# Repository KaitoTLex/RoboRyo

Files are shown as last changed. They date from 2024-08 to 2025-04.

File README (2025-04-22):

This is the Robo Ryo Repository

The RoboRyo is a more redundant clone of National Intstrument's RoboRio. It provides long range controls and less BS compared to the FRC legal RoboRio. The upside of RoboRyo is that there are more configurable ports compared to the real RoboRyo and it also includes quality of Life features that the real RoboRio dosen't have. 

This document gives you an overview of the RoboRyo repository and how it works 

Contributers

The RoboRyo PCB is designed by KaitoTLex(Ren Lin)
The RoboRyo Code is developed by Nichloas Luo

This project is licened under the MIT License

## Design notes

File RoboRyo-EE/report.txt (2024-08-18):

Info: Processing symbol 'C1:CAPC1608X90N'.
Info: Processing symbol 'DO7:26011102'.
Info: Processing symbol 'C2:CAPC0603X33N'.
Info: Processing symbol 'J4:26011103'.
Info: Processing symbol 'C3:CAPC0603X33N'.
Info: Processing symbol 'J3:26011103'.
Info: Processing symbol 'C4:CAPC0603X33N'.
Info: Processing symbol 'J2:26011103'.
Info: Processing symbol 'C5:CAPC0603X33N'.
Info: Processing symbol 'J1:26011103'.
Info: Processing symbol 'C6:CAPC0603X33N'.
Info: Processing symbol 'IC3:LD29080DT50R'.
Info: Processing symbol 'C9:CAPC0603X33N'.
Info: Processing symbol 'IC2:TO228P972X240-3N'.
Info: Processing symbol 'C13:CAPC0603X33N'.
Info: Processing symbol 'IC1:XB24CAWIT001'.
Info: Processing symbol 'C14:CAPC1608X90N'.
Info: Processing symbol 'DO1:26011102'.
Info: Processing symbol 'C16:CAPC1608X90N'.
Info: Processing symbol 'DO12:26011102'.
Info: Processing symbol 'CAN1:26011102'.
Info: Processing symbol 'DO2:26011102'.
Info: Processing symbol 'D1:DIOAD1910W86L670D310'.
Info: Processing symbol 'DO8:26011102'.
Info: Processing symbol 'D2:DIOAD1910W86L670D310'.
Info: Processing symbol 'DO3:26011102'.
Info: Processing symbol 'D3:DIOAD1910W86L670D310'.
Info: Processing symbol 'DO11:26011102'.
Info: Processing symbol 'D6:DIOAD1910W86L670D310'.
Info: Processing symbol 'DO4:26011102'.
Info: Processing symbol 'D7:DIOAD1910W86L670D310'.
Info: Processing symbol 'DO9:26011102'.
Info: Processing symbol 'D8:DIOAD1910W86L670D310'.
Info: Processing symbol 'DO5:26011102'.
Info: Processing symbol 'D9:DIOAD1910W86L670D310'.
Info: Processing symbol 'DO13:26011102'.
Info: Processing symbol 'D10:DIOAD1910W86L670D310'.
Info: Processing symbol 'DO6:26011102'.
Info: Processing symbol 'D11:DIOAD1910W86L670D310'.
Info: Processing symbol 'DO10:26011102'.
Info: Processing symbol 'D12:DIOAD1910W86L670D310'.
Info: Processing symbol 'J5:26011103'.
Info: Processing symbol 'J6:26011103'.
Info: Processing symbol 'J7:26011103'.
Info: Processing symbol 'J8:26011103'.
Info: Processing symbol 'LED1-A1:LEDC1608X80N'.
Info: Processing symbol 'LED1-B1:LEDC1608X80N'.
Info: Processing symbol 'LED1-G1:LEDC1608X80N'.
Info: Processing symbol 'LED1-R1:LEDC1608X80N'.
Info: Processing symbol 'LED1-Y1:LEDC1608X80N'.
Info: Processing symbol 'PowerIN1:26011502'.
Info: Processing symbol 'U4:Package_LGA:LGA-28_5.2x3.8mm_P0.5mm'.
Info: Processing symbol 'Q1:SOIC127P600X175-8N'.
Info: Processing symbol 'Q2:SOIC127P600X175-8N'.
Info: Processing symbol 'Q3:SOIC127P600X175-8N'.
Info: Processing symbol 'Q4:SOIC127P600X175-8N'.
Info: Processing symbol 'Q5:SOIC127P600X175-8N'.
Info: Processing symbol 'Q7:CSD13383F4'.
Info: Processing symbol 'R1:ERJ3EKF1000V'.
Info: Processing symbol 'R2:ERJ3EKF1000V'.
Info: Processing symbol 'R3:ERJ3EKF1000V'.
Info: Processing symbol 'R4:ERJ3EKF1000V'.
Info: Processing symbol 'R5:RESC1005X40N'.
Info: Processing symbol 'R6:ERJ2RKD1004X'.
Info: Processing symbol 'R7:ERJ2RKD1004X'.
Info: Processing symbol 'RSL1:APHHS1005SECK'.
Info: Processing symbol 'S1:KSS'.
Info: Processing symbol 'U1:Package_QFP:LQFP-64_10x10mm_P0.5mm'.
Change IC1 footprint from 'SamacSys_Parts:XB24CAWIT001' to 'XB24CAWIT001'.
Add IC2 (footprint 'TO228P972X240-3N').
Add IC3 (footprint 'LD29080DT50R').
Change C1 footprint from 'SamacSys_Parts:CAPC1608X90N' to 'CAPC1608X90N'.
Change C14 footprint from 'SamacSys_Parts:CAPC1608X90N' to 'CAPC1608X90N'.
Change C16 footprint from 'SamacSys_Parts:CAPC1608X90N' to 'CAPC1608X90N'.
Change CAN1 footprint from 'SamacSys_Parts:26011102' to '26011102'.
Change D1 footprint from 'SamacSys_Parts:DIOAD1910W86L670D310' to 'DIOAD1910W86L670D310'.
Change D2 footprint from 'SamacSys_Parts:DIOAD1910W86L670D310' to 'DIOAD1910W86L670D310'.
Change D3 footprint from 'SamacSys_Parts:DIOAD1910W86L670D310' to 'DIOAD1910W86L670D310'.
Change D6 footprint from 'SamacSys_Parts:DIOAD1910W86L670D310' to 'DIOAD1910W86L670D310'.
Change D7 footprint from 'SamacSys_Parts:DIOAD1910W86L670D310' to 'DIOAD1910W86L670D310'.
Change D8 footprint from 'SamacSys_Parts:DIOAD1910W86L670D310' to 'DIOAD1910W86L670D310'.
Change D9 footprint from 'SamacSys_Parts:DIOAD1910W86L670D310' to 'DIOAD1910W86L670D310'.
Change D10 footprint from 'SamacSys_Parts:DIOAD1910W86L670D310' to 'DIOAD1910W86L670D310'.
Add Q1 (footprint 'SOIC127P600X175-8N').
Change D11 footprint from 'SamacSys_Parts:DIOAD1910W86L670D310' to 'DIOAD1910W86L670D310'.
Add Q2 (footprint 'SOIC127P600X175-8N').
Change D12 footprint from 'SamacSys_Parts:DIOAD1910W86L670D310' to 'DIOAD1910W86L670D310'.
Add Q3 (footprint 'SOIC127P600X175-8N').
Change DO1 footprint from 'SamacSys_Parts:26011102' to '26011102'.
Add Q4 (footprint 'SOIC127P600X175-8N').
Change DO2 footprint from 'SamacSys_Parts:26011102' to '26011102'.
Add Q5 (footprint 'SOIC127P600X175-8N').
Change DO3 footprint from 'SamacSys_Parts:26011102' to '26011102'.
Add Q7 (footprint 'CSD13383F4').
Change DO4 footprint from 'SamacSys_Parts:26011102' to '26011102'.
Change DO5 footprint from 'SamacSys_Parts:26011102' to '26011102'.
Change DO6 footprint from 'SamacSys_Parts:26011102' to '26011102'.
Change DO7 footprint from 'SamacSys_Parts:26011102' to '26011102'.
Change DO8 footprint from 'SamacSys_Parts:26011102' to '26011102'.
Change R5 footprint from 'SamacSys_Parts:RESC1005X40N' to 'RESC1005X40N'.
Change DO9 footprint from 'SamacSys_Parts:26011102' to '26011102'.
Change R6 footprint from 'SamacSys_Parts:ERJ2RKD1004X' to 'ERJ2RKD1004X'.
Change DO10 footprint from 'SamacSys_Parts:26011102' to '26011102'.
Change R7 footprint from 'SamacSys_Parts:ERJ2RKD1004X' to 'ERJ2RKD1004X'.
Change DO11 footprint from 'SamacSys_Parts:26011102' to '26011102'.
Add RSL1 (footprint 'APHHS1005SECK').
Change DO12 footprint from 'SamacSys_Parts:26011102' to '26011102'.
Add S1 (footprint 'KSS').
Change DO13 footprint from 'SamacSys_Parts:26011102' to '26011102'.
Error: Cannot add J8 (footprint '26011103' not found).
Error: Cannot add J1 (footprint '26011103' not found).
Error: Cannot add LED1-A1 (footprint 'LEDC1608X80N' not found).
Error: Cannot add C4 (footprint 'CAPC0603X33N' not found).
Error: Cannot add LED1-B1 (footprint 'LEDC1608X80N' not found).
Error: Cannot add J2 (footprint '26011103' not found).
Error: Cannot add R1 (footprint 'ERJ3EKF1000V' not found).
Error: Cannot add LED1-G1 (footprint 'LEDC1608X80N' not found).
Error: Cannot add PowerIN1 (footprint '26011502' not found).
Error: Cannot add C3 (footprint 'CAPC0603X33N' not found).
Error: Cannot add R3 (footprint 'ERJ3EKF1000V' not found).
Error: Cannot add LED1-R1 (footprint 'LEDC1608X80N' not found).
Error: Cannot add R4 (footprint 'ERJ3EKF1000V' not found).
Error: Cannot add J3 (footprint '26011103' not found).
Error: Cannot add LED1-Y1 (footprint 'LEDC1608X80N' not found).
Error: Cannot add C2 (footprint 'CAPC0603X33N' not found).
Error: Cannot add J4 (footprint '26011103' not found).
Error: Cannot add C13 (footprint 'CAPC0603X33N' not found).
Error: Cannot add J5 (footprint '26011103' not found).
Error: Cannot add C6 (footprint 'CAPC0603X33N' not found).
Error: Cannot add J6 (footprint '26011103' not found).
Error: Cannot add C9 (footprint 'CAPC0603X33N' not found).
Error: Cannot add J7 (footprint '26011103' not found).
Error: Cannot add C5 (footprint 'CAPC0603X33N' not found).
Error: Cannot add R2 (footprint 'ERJ3EKF1000V' not found).

Info: Total warnings: 0, errors: 25.

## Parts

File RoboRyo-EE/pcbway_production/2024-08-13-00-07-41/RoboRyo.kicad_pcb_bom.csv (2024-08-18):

Designator | Quantity | Value | Footprint | Package | MPN | DNP | Mount_Type | Description | Height | Manufacturer_Name | Mouser Part Number | Mouser Price/Stock | Arrow Part Number | Arrow Price/Stock
C1, C16 | 2 | CL10A475KP8NNNC | CAPC1608X90N |  | CL10A475KP8NNNC |  | smt | Multilayer Ceramic Capacitors MLCC - SMD/SMT | 0.9 | SAMSUNG | 187-CL10A475KP8NNNC | https://www.mouser.co.uk/ProductDetail/Samsung-Electro-Mechanics/CL10A475KP8NNNC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 | CL10A475KP8NNNC | https://www.arrow.com/en/products/cl10a475kp8nnnc/samsung-electro-mechanics?region=europe
C13, C2, C3, C4, C5, C6, C9 | 7 | CL03A104KQ3NNNC | CAPC0603X33N |  | CL03A104KQ3NNNC |  | smt | Samsung Electro-Mechanics 0201 CL 100nF Ceramic Multilayer Capacitor, 6.3 V, +85C, X5R Dielectric, +/-10% SMD | 0.33 | SAMSUNG | 187-CL03A104KQ3NNNC | https://www.mouser.co.uk/ProductDetail/Samsung-Electro-Mechanics/CL03A104KQ3NNNC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 | CL03A104KQ3NNNC | https://www.arrow.com/en/products/cl03a104kq3nnnc/samsung-electro-mechanics?region=nac
C14 | 1 | CL10B105KP8NNNC | CAPC1608X90N |  | CL10B105KP8NNNC |  | smt | 1F +/-10% 10V Ceramic Capacitor X7R 0603 (1608 Metric) | 0.9 | SAMSUNG | 187-CL10B105KP8NNNC | https://www.mouser.co.uk/ProductDetail/Samsung-Electro-Mechanics/CL10B105KP8NNNC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 | CL10B105KP8NNNC | https://www.arrow.com/en/products/cl10b105kp8nnnc/samsung-electro-mechanics?region=europe
CAN1, DO1, DO10, DO11, DO12, DO13, DO2, DO3, DO4, DO5, DO6, DO7, DO8, DO9 | 14 | 2601-1102 | 26011102 |  | 2601-1102 |  | tht | PCB terminal block; lever; 1.5 mm; Pin spacing 3.5 mm; 2-pole; Push-in CAGE CLAMP; 1,50 mm; gray | 12.75 | Wago
D1, D10, D11, D12, D2, D3, D6, D7, D8, D9 | 10 | SB240 | DIOAD1910W86L670D310 |  | SB240 |  | tht | Power Schottky (IF1A) - SB240 , Standard, 40V, 2A, DO-15 |  | PANJIT
IC1 | 1 | XB24CAWIT-001 | XB24CAWIT001 |  | XB24CAWIT-001 |  | tht | 802.15.4 Transceiver Module 2.4GHz Integrated, Wire Antenna Through Hole | 29.845 | DIGI | 888-XB24CAWIT-001 | https://www.mouser.co.uk/ProductDetail/DIGI/XB24CAWIT-001?qs=%2FPVulymFwT1u0cCwuRVF0g%3D%3D
IC2 | 1 | LD29080DT33R | TO228P972X240-3N |  | LD29080DT33R |  | smt | LD29080DT33R, Low Dropout Voltage Regulator, 0.8A, 3.3 V +/-1%, 2.5 13 Vin, 3-Pin DPAK | 2.4 | STMicroelectronics | 511-LD29080DT33R | https://www.mouser.co.uk/ProductDetail/STMicroelectronics/LD29080DT33R?qs=k9dH%2Fx4GHJAkjytoj9%252B3%2Fw%3D%3D
IC3 | 1 | LD29080DT50R | LD29080DT50R |  | LD29080DT50R |  | smt | 800 mA fixed and adjustable output very low drop voltage regulator | 2.63 | STMicroelectronics | 511-LD29080DT50R | https://www.mouser.co.uk/ProductDetail/STMicroelectronics/LD29080DT50R?qs=22WmWNTp1rrXQIBxhkME0A%3D%3D | LD29080DT50R | https://www.arrow.com/en/products/ld29080dt50r/stmicroelectronics?region=nac
J1, J2, J3, J4, J5, J6, J7, J8 | 8 | 2601-1103_000-004 | 26011103 |  | 2601-1103/000-004 |  | tht | PCB terminal block; lever; 1.5 mm; Pin spacing 3.5 mm; 3-pole; Push-in CAGE CLAMP; 1,50 mm; gray | 12.75 | Wago
LED1-A1 | 1 | 150060AS75000 | LEDC1608X80N |  | 150060AS75000 |  | smt | 2.4 V Amber LED 1608 (0603) SMD, Wurth Elektronik WL-SMCW 150060AS75000 | 0.8 | Wurth Elektronik | 710-150060AS75000 | https://www.mouser.co.uk/ProductDetail/Wurth-Elektronik/150060AS75000?qs=d0WKAl%252BL4KbvMBYryeof0Q%3D%3D
LED1-B1 | 1 | 150060BS75000 | LEDC1608X80N |  | 150060BS75000 |  | smt | LED,Wurth Elektronik,150060BS75000 Wurth Elektronik 150060BS75000, WL-SMCW Series Blue LED, 470 nm 1608 (0603) Clear, Rectangle Lens SMD package | 0.8 | Wurth Elektronik | 710-150060BS75000 | https://www.mouser.co.uk/ProductDetail/Wurth-Elektronik/150060BS75000?qs=LlUlMxKIyB2DLLpXQThavA%3D%3D
LED1-G1 | 1 | 150060GS75000 | LEDC1608X80N |  | 150060GS75000 |  | smt | Wurth Elektronik WL-SMCW 520 nm Green LED, 1608 (0603) Clear SMD package | 0.8 | Wurth Elektronik | 710-150060GS75000 | https://www.mouser.co.uk/ProductDetail/Wurth-Elektronik/150060GS75000?qs=LlUlMxKIyB0UYkq5lDO8nA%3D%3D
LED1-R1 | 1 | 150060RS75000 | LEDC1608X80N |  | 150060RS75000 |  | smt | WURTH ELEKTRONIK - 150060RS75000 - LED, 0603, RED, 250MCD, 625NM | 0.8 | Wurth Elektronik | 710-150060RS75000 | https://www.mouser.co.uk/ProductDetail/Wurth-Elektronik/150060RS75000?qs=LlUlMxKIyB3QnmZ3fw%2FVCA%3D%3D
LED1-Y1 | 1 | 150060YS75000 | LEDC1608X80N |  | 150060YS75000 |  | smt | LED,Wurth Elektronik,150060YS75000 Wurth Elektronik 150060YS75000, WL-SMCW Series Yellow LED, 590 nm, 1608 (0603) Clear, Rectangle Lens SMD Package | 0.8 | Wurth Elektronik | 710-150060YS75000 | https://www.mouser.co.uk/ProductDetail/Wurth-Elektronik/150060YS75000?qs=LlUlMxKIyB0nKmwefHgtZw%3D%3D
PowerIN1 | 1 | 2601-1502 | 26011502 |  | 2601-1502 |  | tht | PCB terminal block; lever; 1.5 mm; Pin spacing 11.5 mm; 2-pole; Push-in CAGE CLAMP | 12.75 | Wago
Q1, Q2, Q3, Q4, Q5 | 5 | DMG9926USD-13 | SOIC127P600X175-8N |  | DMG9926USD-13 |  | smt | Diodes Inc DMG9926USD-13 Dual N-channel MOSFET Transistor, 8 A, 20 V, 8-Pin SOP | 1.75 | Diodes Incorporated | 621-DMG9926USD-13 | https://www.mouser.co.uk/ProductDetail/Diodes-Incorporated/DMG9926USD-13?qs=4YT44p7w2buzSaF0raP1iw%3D%3D
Q7 | 1 | CSD13383F4 | CSD13383F4 |  | CSD13383F4 |  | smt | 12V, N ch NexFET MOSFET, single LGA 1.0 x 0.6mm, 44mOhm | 0.35 | Texas Instruments | 595-CSD13383F4 | https://www.mouser.co.uk/ProductDetail/Texas-Instruments/CSD13383F4?qs=beZBGHSk9c3rR5p9cfIBEg%3D%3D | CSD13383F4 | https://www.arrow.com/en/products/csd13383f4/texas-instruments?region=nac
R1, R2, R3, R4 | 4 | ERJ3GEYJ102V | ERJ3EKF1000V |  | ERJ3GEYJ102V |  | smt | Thick Film Resistors - SMD 0603 1Kohms 5% AEC-Q200 | 0.55 | Panasonic | 667-ERJ-3GEYJ102V | http://www.mouser.com/Search/ProductDetail.aspx?qs=66DK8nO8gJBFiTsClorqsA%3d%3d
R5 | 1 | RC1005F103CS | RESC1005X40N |  | RC1005F103CS |  | smt | Thick Film General Chip Resistor | 0.4 | SAMSUNG | N/A | https://www.mouser.com/Search/Refine.aspx?Keyword=N%2FA | RC1005F103CS | https://www.arrow.com/en/products/rc1005f103cs/samsung-electro-mechanics?region=nac
R6, R7 | 2 | ERJ-2RKF1001X | ERJ2RKD1004X |  | ERJ-2RKF1001X |  | smt | Thick Film Resistors - SMD 0402 1Kohms 1% AEC-Q200 | 0.4 | Panasonic | 667-ERJ-2RKF1001X | https://www.mouser.co.uk/ProductDetail/Panasonic/ERJ-2RKF1001X?qs=H7k1u0Mp9JRRg22R5LYj9Q%3D%3D | ERJ-2RKF1001X | https://www.arrow.com/en/products/erj-2rkf1001x/panasonic?region=nac
RSL1 | 1 | APHHS1005SECK | APHHS1005SECK |  | APHHS1005SECK |  | smt | Standard LEDs - SMD ORANGE WTR CLEAR 160mcd 610nm | 0.6 | Kingbright | 604-APHHS1005SECK | https://www.mouser.co.uk/ProductDetail/Kingbright/APHHS1005SECK?qs=48MD8zkHsZDIjCNVxt6Sow%3D%3D | APHHS1005SECK | https://www.arrow.com/en/products/aphhs1005seck/kingbright?region=nac
S1 | 1 | KSS243GLFG | KSS |  | KSS243GLFG |  | smt | KSS243GLFG (Tactile Switches) |  | C & K COMPONENTS | 611-KSS243GLFG | https://www.mouser.co.uk/ProductDetail/CK/KSS243GLFG?qs=vOd3edNlRKCYwSRGjGPkbw%3D%3D | KSS243GLFG | https://www.arrow.com/en/products/kss243glfg/ck
U1 | 1 | STM32F446RETx | LQFP-64_10x10mm_P0.5mm |  |  |  | smt | STMicroelectronics Arm Cortex-M4 MCU, 512KB flash, 128KB RAM, 180 MHz, 1.8-3.6V, 50 GPIO, LQFP64
U4 | 1 | BNO055 | LGA-28_5.2x3.8mm_P0.5mm |  |  |  | smt | Intelligent 9-axis absolute orientation sensor, LGA-28

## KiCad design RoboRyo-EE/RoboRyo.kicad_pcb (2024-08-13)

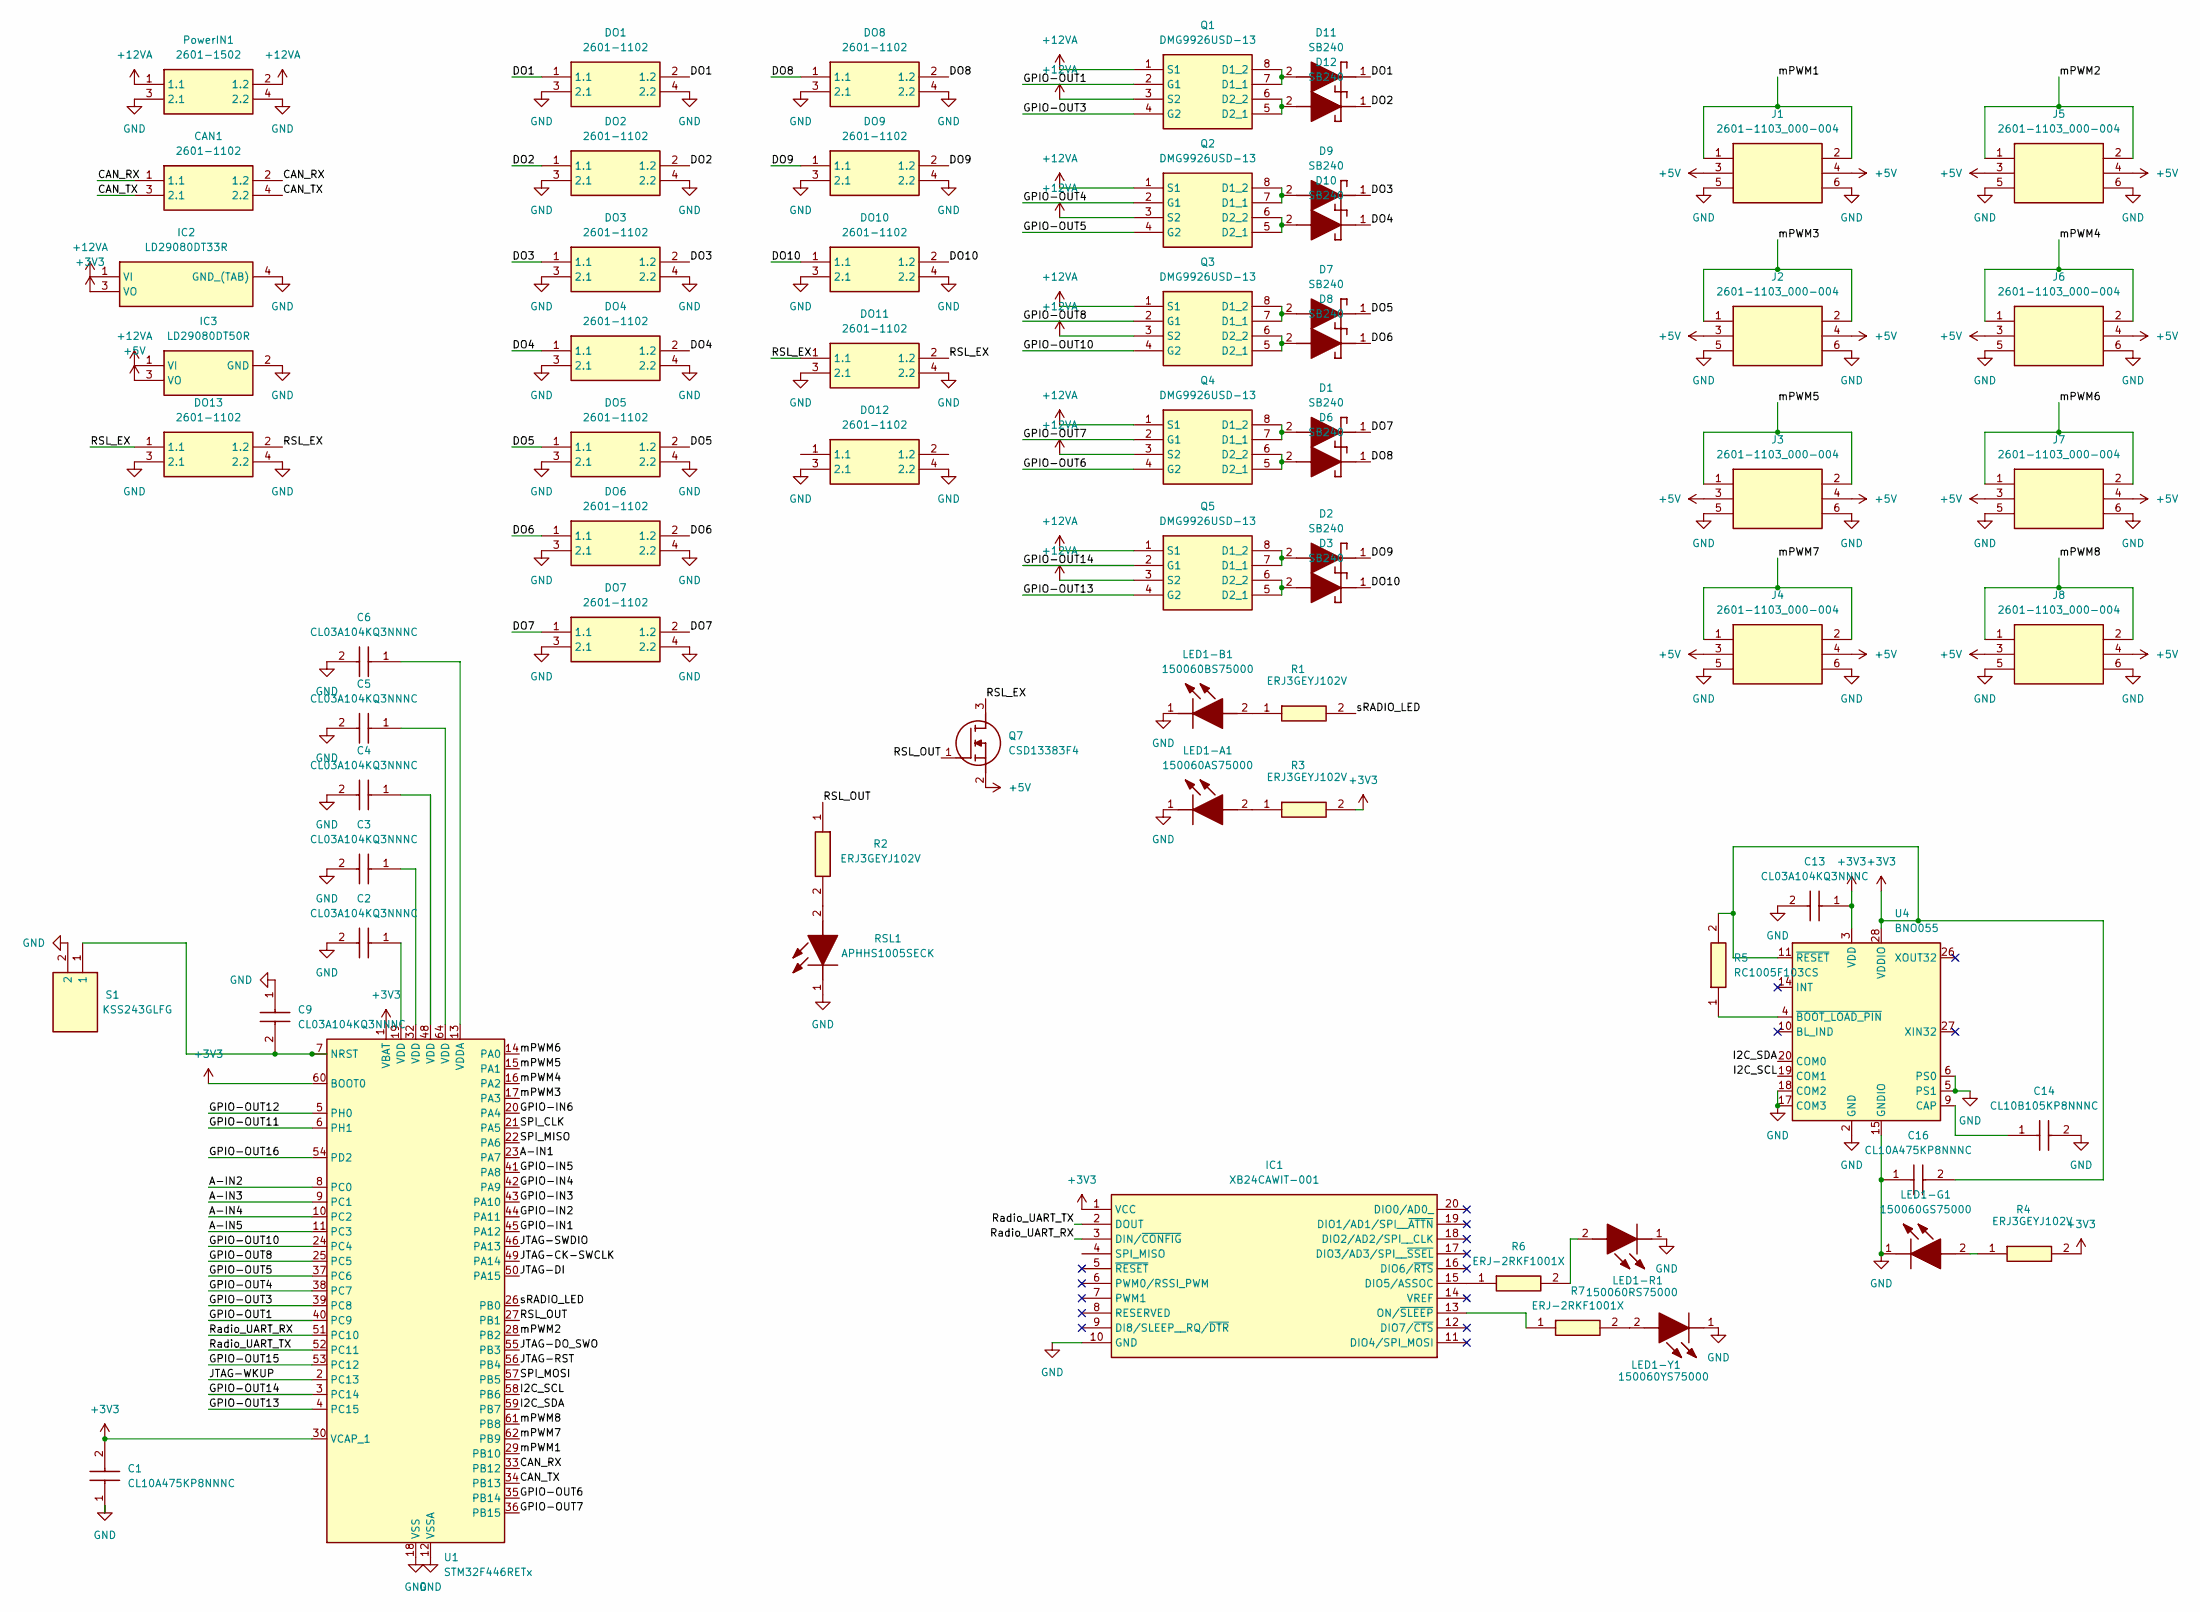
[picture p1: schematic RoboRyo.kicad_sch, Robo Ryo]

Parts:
C1, C16: CL10A475KP8NNNC; CAPC1608X90N; Manufacturer_Part_Number CL10A475KP8NNNC; Mouser Part Number 187-CL10A475KP8NNNC
C2, C3, C4, C5, C6, C9, C13: CL03A104KQ3NNNC; CAPC0603X33N; Manufacturer_Part_Number CL03A104KQ3NNNC; Mouser Part Number 187-CL03A104KQ3NNNC
C14: CL10B105KP8NNNC; CAPC1608X90N; Manufacturer_Part_Number CL10B105KP8NNNC; Mouser Part Number 187-CL10B105KP8NNNC
CAN1: 2601-1102; 26011102; Manufacturer_Part_Number 2601-1102
D1, D2, D3, D6, D7, D8, D9, D10, D11, D12: SB240; DIOAD1910W86L670D310; Manufacturer_Part_Number SB240
DO1, DO2, DO3, DO4, DO5, DO6, DO7, DO8, DO9, DO10, DO11, DO12, DO13: 2601-1102; 26011102; Manufacturer_Part_Number 2601-1102
IC1: XB24CAWIT-001; XB24CAWIT001; Mouser Part Number 888-XB24CAWIT-001
IC2: LD29080DT33R; TO228P972X240-3N; Mouser Part Number 511-LD29080DT33R
IC3: LD29080DT50R; Manufacturer_Part_Number LD29080DT50R; Mouser Part Number 511-LD29080DT50R
J1, J2, J3, J4, J5, J6, J7, J8: 2601-1103_000-004; 26011103; Manufacturer_Part_Number 2601-1103/000-004
LED1-A1: 150060AS75000; LEDC1608X80N; Manufacturer_Part_Number 150060AS75000; Mouser Part Number 710-150060AS75000
LED1-B1: 150060BS75000; LEDC1608X80N; Manufacturer_Part_Number 150060BS75000; Mouser Part Number 710-150060BS75000
LED1-G1: 150060GS75000; LEDC1608X80N; Manufacturer_Part_Number 150060GS75000; Mouser Part Number 710-150060GS75000
LED1-R1: 150060RS75000; LEDC1608X80N; Manufacturer_Part_Number 150060RS75000; Mouser Part Number 710-150060RS75000
LED1-Y1: 150060YS75000; LEDC1608X80N; Manufacturer_Part_Number 150060YS75000; Mouser Part Number 710-150060YS75000
PowerIN1: 2601-1502; 26011502; Manufacturer_Part_Number 2601-1502
Q1, Q2, Q3, Q4, Q5: DMG9926USD-13; SOIC127P600X175-8N; Mouser Part Number 621-DMG9926USD-13
Q7: CSD13383F4; Manufacturer_Part_Number CSD13383F4; Mouser Part Number 595-CSD13383F4
R1, R2, R3, R4: ERJ3GEYJ102V; ERJ3EKF1000V; Manufacturer_Part_Number ERJ3GEYJ102V; Mouser Part Number 667-ERJ-3GEYJ102V
R5: RC1005F103CS; RESC1005X40N; Manufacturer_Part_Number RC1005F103CS; Mouser Part Number N/A
R6, R7: ERJ-2RKF1001X; ERJ2RKD1004X; Manufacturer_Part_Number ERJ-2RKF1001X; Mouser Part Number 667-ERJ-2RKF1001X
RSL1: APHHS1005SECK; Manufacturer_Part_Number APHHS1005SECK; Mouser Part Number 604-APHHS1005SECK
S1: KSS243GLFG; KSS; Manufacturer_Part_Number KSS243GLFG; Mouser Part Number 611-KSS243GLFG
U1: STM32F446RETx; LQFP-64_10x10mm_P0.5mm
U4: BNO055; LGA-28_5.2x3.8mm_P0.5mm

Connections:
+3V3: C1.2, C13.1, C16.2, IC1.1 (VCC), IC2.3 (VO), R3.2, R4.2, R5.2, U1.1 (VBAT), U1.30 (VCAP_1), U1.60 (BOOT0), U4.3 (VDD), U4.11 (~RESET), U4.28 (VDDIO)
+5V: IC3.3 (VO), J1.3 (2.1), J1.4 (2.2), J2.3 (2.1), J2.4 (2.2), J3.3 (2.1), J3.4 (2.2), J4.3 (2.1), J4.4 (2.2), J5.3 (2.1), J5.4 (2.2), J6.3 (2.1), J6.4 (2.2), J7.3 (2.1), J7.4 (2.2), J8.3 (2.1), J8.4 (2.2), Q7.2 (S)
+12VA: IC2.1 (VI), IC3.1 (VI), PowerIN1.1 (1.1), PowerIN1.2 (1.2), Q1.1 (S1), Q1.3 (S2), Q2.1 (S1), Q2.3 (S2), Q3.1 (S1), Q3.3 (S2), Q4.1 (S1), Q4.3 (S2), Q5.1 (S1), Q5.3 (S2)
/A-IN1: U1.23 (PA7)
/A-IN2: U1.8 (PC0)
/A-IN3: U1.9 (PC1)
/A-IN4: U1.10 (PC2)
/A-IN5: U1.11 (PC3)
/CAN_RX: CAN1.1 (1.1), CAN1.2 (1.2), U1.33 (PB12)
/CAN_TX: CAN1.3 (2.1), CAN1.4 (2.2), U1.34 (PB13)
/DO1: D11.1 (K), DO1.1 (1.1), DO1.2 (1.2)
/DO2: D12.1 (K), DO2.1 (1.1), DO2.2 (1.2)
/DO3: D9.1 (K), DO3.1 (1.1), DO3.2 (1.2)
/DO4: D10.1 (K), DO4.1 (1.1), DO4.2 (1.2)
/DO5: D7.1 (K), DO5.1 (1.1), DO5.2 (1.2)
/DO6: D8.1 (K), DO6.1 (1.1), DO6.2 (1.2)
/DO7: D1.1 (K), DO7.1 (1.1), DO7.2 (1.2)
/DO8: D6.1 (K), DO8.1 (1.1), DO8.2 (1.2)
/DO9: D2.1 (K), DO9.1 (1.1), DO9.2 (1.2)
/DO10: D3.1 (K), DO10.1 (1.1), DO10.2 (1.2)
/GPIO-IN1: U1.45 (PA12)
/GPIO-IN2: U1.44 (PA11)
/GPIO-IN3: U1.43 (PA10)
/GPIO-IN4: U1.42 (PA9)
/GPIO-IN5: U1.41 (PA8)
/GPIO-IN6: U1.20 (PA4)
/GPIO-OUT1: Q1.2 (G1), U1.40 (PC9)
/GPIO-OUT3: Q1.4 (G2), U1.39 (PC8)
/GPIO-OUT4: Q2.2 (G1), U1.38 (PC7)
/GPIO-OUT5: Q2.4 (G2), U1.37 (PC6)
/GPIO-OUT6: Q4.4 (G2), U1.35 (PB14)
/GPIO-OUT7: Q4.2 (G1), U1.36 (PB15)
/GPIO-OUT8: Q3.2 (G1), U1.25 (PC5)
/GPIO-OUT10: Q3.4 (G2), U1.24 (PC4)
/GPIO-OUT11: U1.6 (PH1)
/GPIO-OUT12: U1.5 (PH0)
/GPIO-OUT13: Q5.4 (G2), U1.4 (PC15)
/GPIO-OUT14: Q5.2 (G1), U1.3 (PC14)
/GPIO-OUT15: U1.53 (PC12)
/GPIO-OUT16: U1.54 (PD2)
/I2C_SCL: U1.58 (PB6), U4.19 (COM1)
/I2C_SDA: U1.59 (PB7), U4.20 (COM0)
/JTAG-CK-SWCLK: U1.49 (PA14)
/JTAG-DI: U1.50 (PA15)
/JTAG-DO_SWO: U1.55 (PB3)
/JTAG-RST: U1.56 (PB4)
/JTAG-SWDIO: U1.46 (PA13)
/JTAG-WKUP: U1.2 (PC13)
/RSL_EX: DO11.1 (1.1), DO11.2 (1.2), DO13.1 (1.1), DO13.2 (1.2), Q7.3 (D)
/RSL_OUT: Q7.1 (G), R2.1, U1.27 (PB1)
/Radio_UART_RX: IC1.3 (DIN/~CONFIG), U1.51 (PC10)
/Radio_UART_TX: IC1.2 (DOUT), U1.52 (PC11)
/SPI_CLK: U1.21 (PA5)
/SPI_MISO: U1.22 (PA6)
/SPI_MOSI: U1.57 (PB5)
/mPWM1: J1.1 (1.1), J1.2 (1.2), U1.29 (PB10)
/mPWM2: J5.1 (1.1), J5.2 (1.2), U1.28 (PB2)
/mPWM3: J2.1 (1.1), J2.2 (1.2), U1.17 (PA3)
/mPWM4: J6.1 (1.1), J6.2 (1.2), U1.16 (PA2)
/mPWM5: J3.1 (1.1), J3.2 (1.2), U1.15 (PA1)
/mPWM6: J7.1 (1.1), J7.2 (1.2), U1.14 (PA0)
/mPWM7: J4.1 (1.1), J4.2 (1.2), U1.62 (PB9)
/mPWM8: J8.1 (1.1), J8.2 (1.2), U1.61 (PB8)
/sRADIO_LED: R1.2, U1.26 (PB0)
GND: C1.1, C2.2, C3.2, C4.2, C5.2, C6.2, C9.1, C13.2, C14.2, C16.1, DO1.3 (2.1), DO1.4 (2.2), DO2.3 (2.1), DO2.4 (2.2), DO3.3 (2.1), DO3.4 (2.2), DO4.3 (2.1), DO4.4 (2.2), DO5.3 (2.1), DO5.4 (2.2), DO6.3 (2.1), DO6.4 (2.2), DO7.3 (2.1), DO7.4 (2.2), DO8.3 (2.1), DO8.4 (2.2), DO9.3 (2.1), DO9.4 (2.2), DO10.3 (2.1), DO10.4 (2.2), DO11.3 (2.1), DO11.4 (2.2), DO12.3 (2.1), DO12.4 (2.2), DO13.3 (2.1), DO13.4 (2.2), IC1.10 (GND), IC2.4 (GND_(TAB)), IC3.2 (GND), J1.5 (3.1), J1.6 (3.2), J2.5 (3.1), J2.6 (3.2), J3.5 (3.1), J3.6 (3.2), J4.5 (3.1), J4.6 (3.2), J5.5 (3.1), J5.6 (3.2), J6.5 (3.1), J6.6 (3.2), J7.5 (3.1), J7.6 (3.2), J8.5 (3.1), J8.6 (3.2), LED1-A1.1 (K), LED1-B1.1 (K), LED1-G1.1 (K), LED1-R1.1 (K), LED1-Y1.1 (K), PowerIN1.3 (2.1), PowerIN1.4 (2.2), RSL1.1 (K), S1.2, U1.12 (VSSA), U1.18 (VSS), U1.31 (VSS), U1.47 (VSS), U1.63 (VSS), U4.2 (GND), U4.5 (PS1), U4.6 (PS0), U4.15 (GNDIO), U4.16 (GNDIO), U4.17 (COM3), U4.18 (COM2), U4.25 (GNDIO)
unnamed: C2.1, U1.19 (VDD)
unnamed: C3.1, U1.32 (VDD)
unnamed: C4.1, U1.48 (VDD)
unnamed: C5.1, U1.64 (VDD)
unnamed: D1.2 (A), Q4.7 (D1_1), Q4.8 (D1_2)
unnamed: D2.2 (A), Q5.7 (D1_1), Q5.8 (D1_2)
unnamed: D3.2 (A), Q5.5 (D2_1), Q5.6 (D2_2)
unnamed: D6.2 (A), Q4.5 (D2_1), Q4.6 (D2_2)
unnamed: D7.2 (A), Q3.7 (D1_1), Q3.8 (D1_2)
unnamed: D8.2 (A), Q3.5 (D2_1), Q3.6 (D2_2)
unnamed: D9.2 (A), Q2.7 (D1_1), Q2.8 (D1_2)
unnamed: D10.2 (A), Q2.5 (D2_1), Q2.6 (D2_2)
unnamed: D11.2 (A), Q1.7 (D1_1), Q1.8 (D1_2)
unnamed: D12.2 (A), Q1.5 (D2_1), Q1.6 (D2_2)
unnamed: IC1.15 (DIO5/ASSOC), R6.1
unnamed: IC1.13 (ON/~SLEEP), R7.1
unnamed: LED1-A1.2 (A), R3.1
unnamed: LED1-B1.2 (A), R1.1
unnamed: LED1-G1.2 (A), R4.1
unnamed: LED1-R1.2 (A), R6.2
unnamed: LED1-Y1.2 (A), R7.2
unnamed: R2.2, RSL1.2 (A)
unnamed: C9.2, S1.1, U1.7 (NRST)
unnamed: C6.1, U1.13 (VDDA)
unnamed: C14.1, U4.9 (CAP)
unnamed: R5.1, U4.4 (~BOOT_LOAD_PIN)

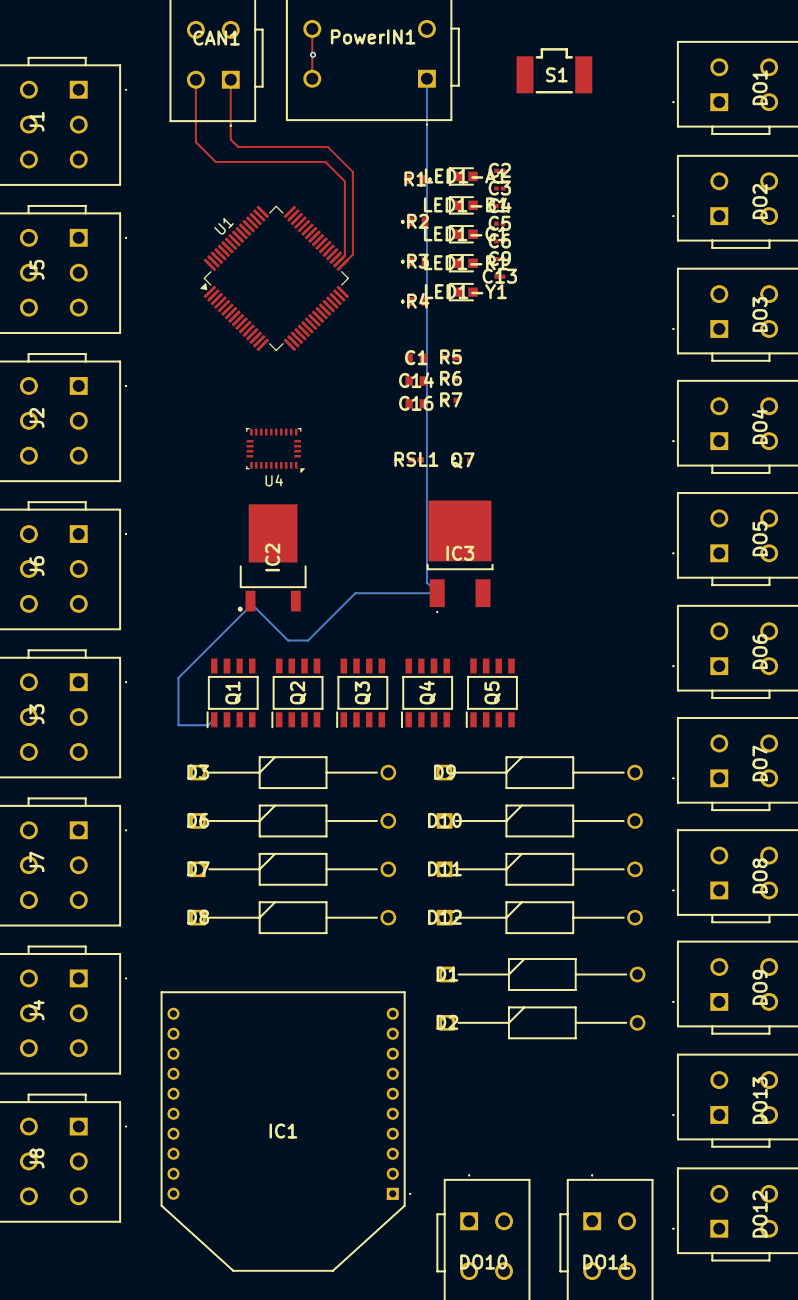
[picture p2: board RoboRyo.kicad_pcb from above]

Board: 4 copper layers, 68 parts (0 on the bottom side), 67 nets.

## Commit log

2024-04-05 RoboRyo-EE commit
    [RoboRyo.kicad_pcb, RoboRyo.kicad_sch]
2024-04-13 Added parts from previous CAD file
    [RoboRyo.kicad_sch]
2024-04-13 Added parts from previous CAD file part 2
    [RoboRyo.kicad_sch]
2024-04-16 added power to STM32F446RETx
    [RoboRyo.kicad_sch]
2024-04-17 added diodes and the PCB is now solonoid ready
    [RoboRyo.kicad_sch]
2024-04-18 added connector ports for PWM
    [RoboRyo.kicad_sch]
2024-04-18 deleted critical power budget vunerability
    [RoboRyo.kicad_sch]
2024-04-18 Added a RSL for safety :nerd:
    [RoboRyo.kicad_sch]
2024-07-20 Sch New: IMU, Radio, PowerConfiguration
    [RoboRyo.kicad_sch]
2024-08-13 Sch Complete, PCB: General Layout complete, wiring left
    [RoboRyo.kicad_pcb, RoboRyo.kicad_sch]
2024-08-18 Sch Edited: I am stupid, PCB:Pending Completition
    [RoboRyo-B_Cu.gbr, RoboRyo-B_Mask.gbr, RoboRyo-B_Paste.gbr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]
